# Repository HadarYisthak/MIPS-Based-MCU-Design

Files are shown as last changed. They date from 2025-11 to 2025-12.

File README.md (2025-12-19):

MIPS-Based MCU Architecture

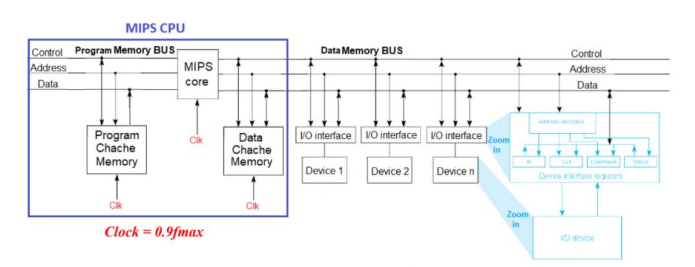
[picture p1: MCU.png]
MIPS MCU Architecture


This project implements a MIPS-based microcontroller (MCU) with Memory-Mapped I/O and interrupt support. It includes a single-cycle CPU core and essential peripheral modules, demonstrating modular microcontroller design in VHDL.

CPU Core (MIPS)
MIPS.vhd: Single-cycle processor executing fetch, decode, execute, memory access, and write-back stages.
Supports arithmetic, logical operations, branching, and memory interactions.

Peripherals
Basic Timer (BasicTimer.vhd): Up/down counting, output compare, interrupts, and PWM support.
GPIO (GPIO.vhd): Handles input/output with buttons, switches, LEDs, and generates interrupts.
Input/Output Peripheral: Separates input and output functionality for efficient communication.
Interrupt Controller (InterruptController.vhd): Manages and prioritizes external interrupts, coordinating with CPU.
Optional Address Decoder (OptAddrDecoder.vhd): Maps addresses to correct peripherals, avoiding conflicts.
Seven-Segment Decoder (SevenSegDecoder.vhd): Displays hexadecimal values on 7-segment display for debugging.

Included Files
MCU.vhd – Top-level entity
MIPS.vhd, IFETCH.vhd, IDECODE.vhd, CONTROL.vhd, ALU_CONTROL.vhd, ALU.vhd, EXECUTE.vhd, DMEMORY.vhd – CPU core modules
BasicTimer.vhd, GPIO.vhd, InputPeripheral.vhd, OutputPeripheral.vhd, InterruptController.vhd, OptAddrDecoder.vhd, SevenSegDecoder.vhd – Peripheral modules

Purpose
This project demonstrates CPU-peripheral interactions, modular microcontroller design, and hands-on VHDL programming skills, making it ideal for learning and experimentation in digital system design.

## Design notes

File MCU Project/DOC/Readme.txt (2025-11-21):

Final Project - MIPS based MCU architecture
This project aim is to design MIPS CPU core with Memory Mapped I/O and Interrupt capability 

## MCU (`MCU.vhd`)
Microcontroller unit. 

BTIMER (BasicTimer.vhd)

The Basic Timer is a dedicated hardware block found in most microcontrollers. Its primary role is straightforward – counting (either upwards or downwards, depending on configuration).
For example, an 8-bit timer will count from 0 up to 255. Once it reaches its maximum, the counter will wrap around and restart from 0.
Typically, timers can be configured through special function registers inside the microcontroller. For instance, instead of rolling over at 255, you might set the timer to reset once it reaches 100. Furthermore, timers are often connected to other hardware resources inside the MCU – for example, automatically toggling an output pin when the timer overflows.
Common timer features include:
Output Compare (OC): change the state of a pin when the timer matches a specific value.
Input Capture (IC): measure how many timer ticks occur between external events.
Pulse Width Modulation (PWM): drive a pin at specific on/off intervals by toggling it at both a match value and on overflow. By adjusting the duty cycle, you can effectively control the amount of power delivered to another device.
We’ll explore these advanced hardware functions in detail later.
For now, we’ll focus on using a timer for time measurement between events (e.g., execution time) as well as for generating basic interrupts.
In our design, the timer is configured to count upwards and to use Output Compare mode with continuous operation.

GPIO (GPIO.vhd)
The General Purpose Input/Output (GPIO) block provides a simple way to interact with the MCU through external devices such as LEDs, switches, and push buttons. It serves as the bridge between the microcontroller and the physical user interface.
Data transfer to and from the GPIO is handled through the system’s BUS lines, allowing both read and write operations as required by the application.
Additionally, the GPIO can be configured to generate interrupts – for example, pressing a button may trigger an interrupt request (IRQ), which the MCU responds to by executing an Interrupt Service Routine (ISR).
This makes the GPIO a flexible module for handling both basic input/output functionality and user-driven events

Interrupt Controller (InterruptController.vhd)
The Interrupt Controller provides support for handling external interrupts generated by hardware peripherals connected to the MCU. These interrupts are managed and prioritized according to the order defined in the project specification.
An interrupt request occurs when a peripheral asserts an IRQ signal. However, the interrupt will only be serviced if the specific interrupt is enabled and no higher-priority interrupt is already in progress.
When an interrupt is accepted, the controller initiates the interrupt handling protocol: the pipeline is stalled, remaining instructions are completed, and the address of the corresponding ISR (Interrupt Service Routine) is placed on the BUS. The actual ISR address is retrieved from memory using the appropriate Mem[type] entry, after which the MCU performs a jump to that location.
Finally, an ACK signal is sent back to confirm that the interrupt request was received and is being serviced by the processor

OptAddrDecoder (OptAddrDecoder.vhd)
The Optional Address Decoder is responsible for mapping a given address to the correct hardware component within the system. Based on the address provided on the BUS, it generates the corresponding chip select signal that activates the relevant peripheral or memory block.
This ensures that only the targeted component responds to the transaction, allowing proper communication and avoiding conflicts between multiple devices connected to the system

OutputPeripheral (OutputPeripheral.vhd)
The Output Peripheral is the part of the GPIO system dedicated specifically to handling output operations.
Its role is to manage and drive the output signals (such as LEDs or other external devices) based on the values written to it through the BUS.
By separating input and output functionality within the GPIO components, this block ensures that all output-related actions are handled in an organized and efficient way.

InputPeripheral (InputPeripheral.vhd)
The Input Peripheral is the part of the GPIO system that manages input operations.
It is responsible for capturing and providing the values from external sources, such as switches, buttons, or other input devices, and making them available to the MCU through the BUS.
This separation of input and output responsibilities within the GPIO ensures clear functionality and simplifies interaction with external hardware.

7 Segment Decoder (SevenSegDecoder.vhd)
The Seven Segment Decoder is responsible for translating a given hexadecimal value into the correct segment combination required to display the corresponding digit or character on the 7-segment display of the DE10 board.
This allows numeric or simple alphanumeric data to be visually represented for debugging or user interaction

MIPS (MIPS.vhd)
The MIPS entity represents a single-cycle MIPS processor. In this architecture, all stages of instruction execution — fetch, decode, execute, memory access, and write-back — are performed within a single clock cycle.
The IFETCH unit retrieves the instruction from the instruction memory using the current PC value and determines the next PC based on sequential execution, jumps, or branches.
The IDECODE unit decodes the fetched instruction, extracts register addresses, reads data from the register file, and computes potential branch or jump targets.
The CONTROL unit generates the required control signals by interpreting the opcode and funct fields, ensuring the correct operation for each instruction type.
The ALU_CONTROL module translates control signals into the specific operation required by the ALU.
The EXECUTE stage performs arithmetic or logical computations through the ALU, including address calculation or data manipulation as required by the instruction.
The DMEMORY unit manages reading from and writing to the data memory (RAM), enabling load and store operations.
Finally, the results are written back into the register file when needed, completing the instruction in a single clock cycle.

Included Files
MIPS.vhd — Top-level entity of the processor
IFETCH.vhd — Instruction fetch logic and PC selection
IDECODE.vhd — Instruction decode logic and register file access
CONTROL.vhd — Main control unit
ALU_CONTROL.vhd — Control signal translator for ALU operations
ALU.vhd — Arithmetic Logic Unit for computations
EXECUTE.vhd — Execution logic for ALU operations and memory addressing
DMEMORY.vhd — Data memory (RAM) interface

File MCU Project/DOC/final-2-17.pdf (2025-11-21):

``

## המערכת

בפרויקט הזה נבנה MCU המכיל MIPS ורכיבים פריפריאליים הפועלים בתיאום כמערכת. המעבד שאותו נעשה הינו מעבד CYCLE SINGLE אותו בנינו במעבדה 5 לצורך הוספת הפקודות התומכות ב ISAשל MIPS לפני מעבר ל PIPELINE.

הרכיבים הפריפריאליים אותם הוספנו הינם GPIO,TIMER BASIC ו CONTROLLER INTERRUPT. המערכת מתקשרת על ידי 3 BUS שונים: ADDRESSBUS,DATABUS ו CONROLBUS.

את המערכת נצרוב על בקר אינטל STANDART 10DE FPGA בו נביא לידי ביטוי את הרצת התוכנית על ידי שימוש בלחצנים, מתגים, נורות, לדים וגל PWM.

המתואר על ידי האיור הבא:

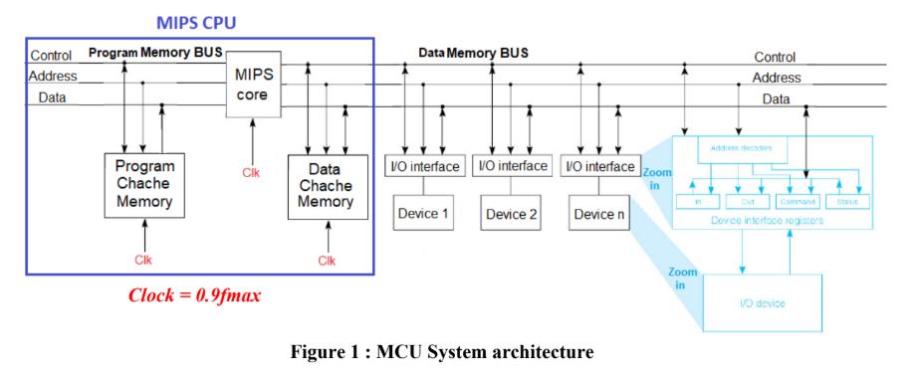
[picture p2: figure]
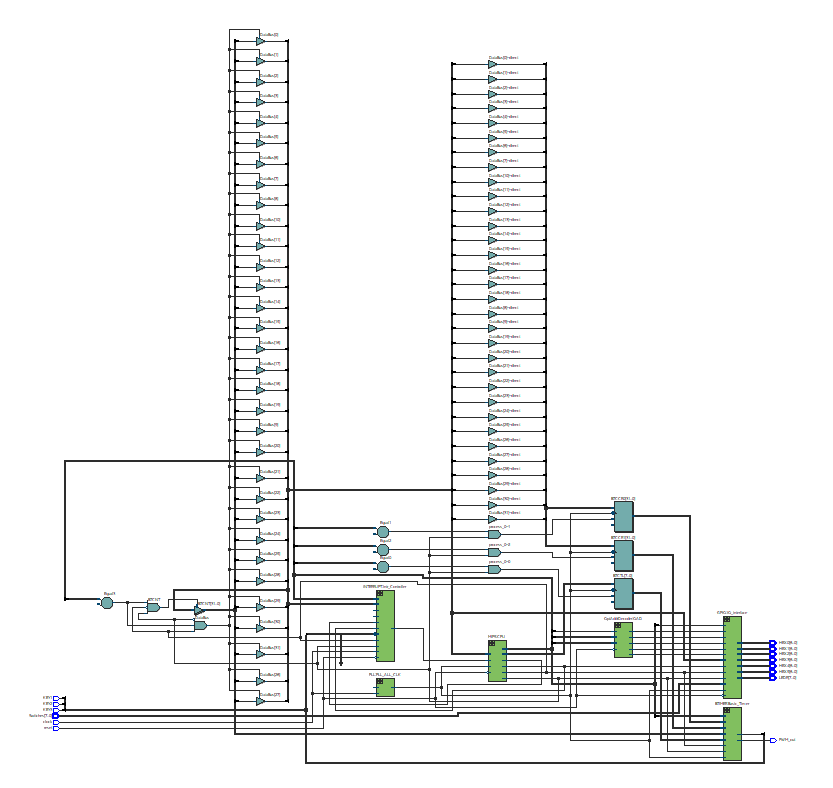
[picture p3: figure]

שרטוט ה RTL של המערכת הינו:

## החלקים השונים של המערכת:

## MIPS

רכיב ה CPU של ה MCU, הינו מעבד CYCLE SINGLE, המבצע את כל שלבי הפעולה תחת אותו מחזור. כלומר מחזור השעון של המעבד נקבע על ידי הפעולה הארוכה ביותר שהיא פעולת ה LW. המעבד יודע לתמוך בסט הפקודות אותן ביקשנו להוציא לפועל.

דיאגרמת RTL של הMIPS:

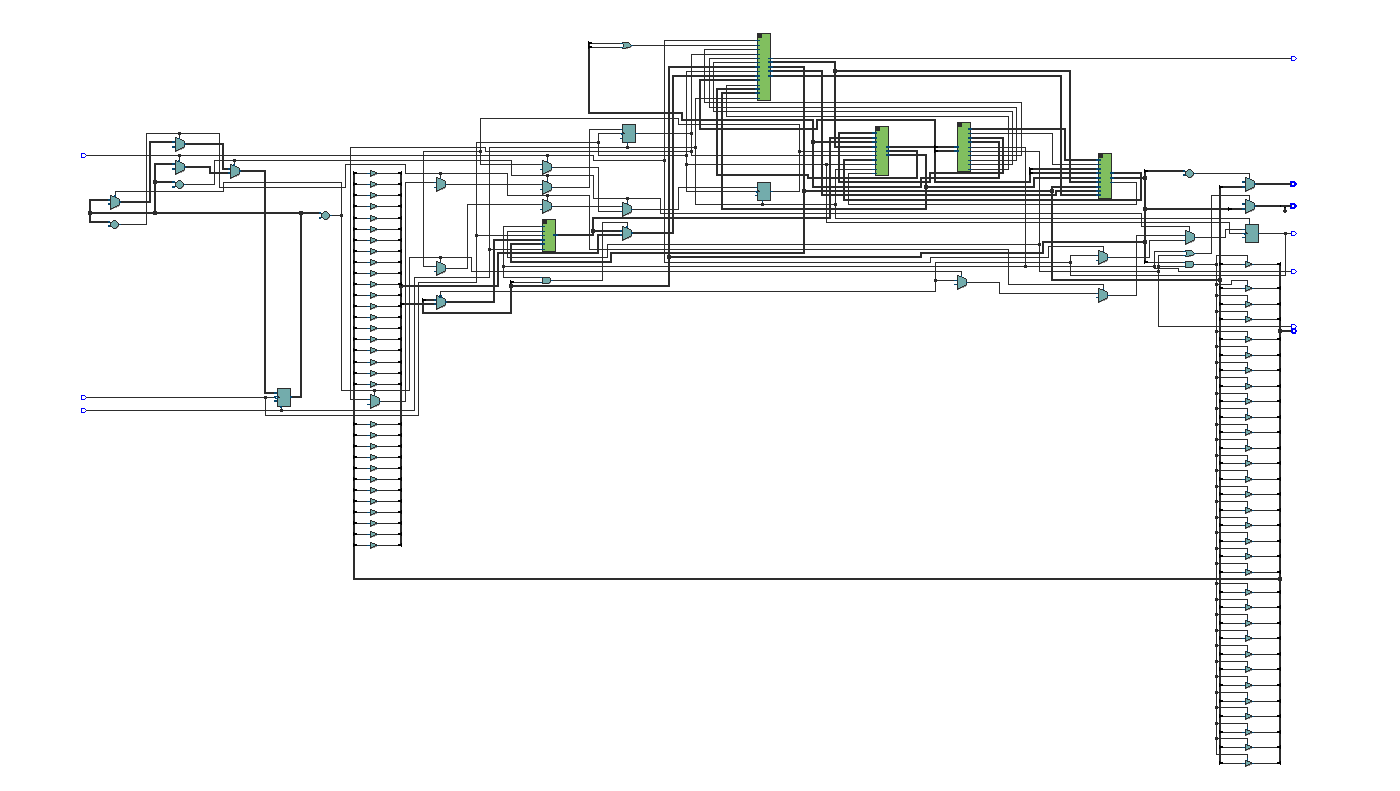
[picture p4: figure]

הלוגיקה שביצענו לעיבוד פקודות במעבד מחולקת לפי שלבי עיבוד הפעולה שהן: ,FETCH DECODE,EXECUTE, DEMEMORY, WRITE BACK.

נפרט פה על שלבי ה פעולה:

:FETCH

בשלב זה נביא את הפקודה המתאימה מתוך ה־ ITCMלפי ערך ה־ PC הנוכחי. במקביל, נחשב גם את ערך ה־ PCלמחזור הבא בעזרת שני MUX:

.1 MUXראשון –בוחר את כתובת ה־ PCהבאה מבין:

- 4 + PCהמשך רצף רגיל
- כתובת מטרה של JUMP
- כתובת מטרה של BRANCH

.2 MUXשני –מקבל כקלט את הפלט של ה־ MUXהראשון, ובוחר בין:

- ה־ PCשנבחר ב־ MUXהראשון
- כתובת היעד של פסיקה (Interrupt(

RTL של שלב ה FETCH:

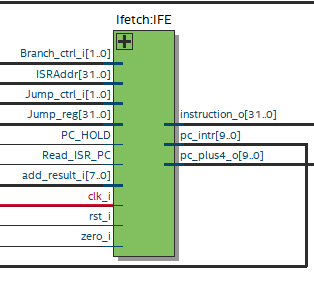
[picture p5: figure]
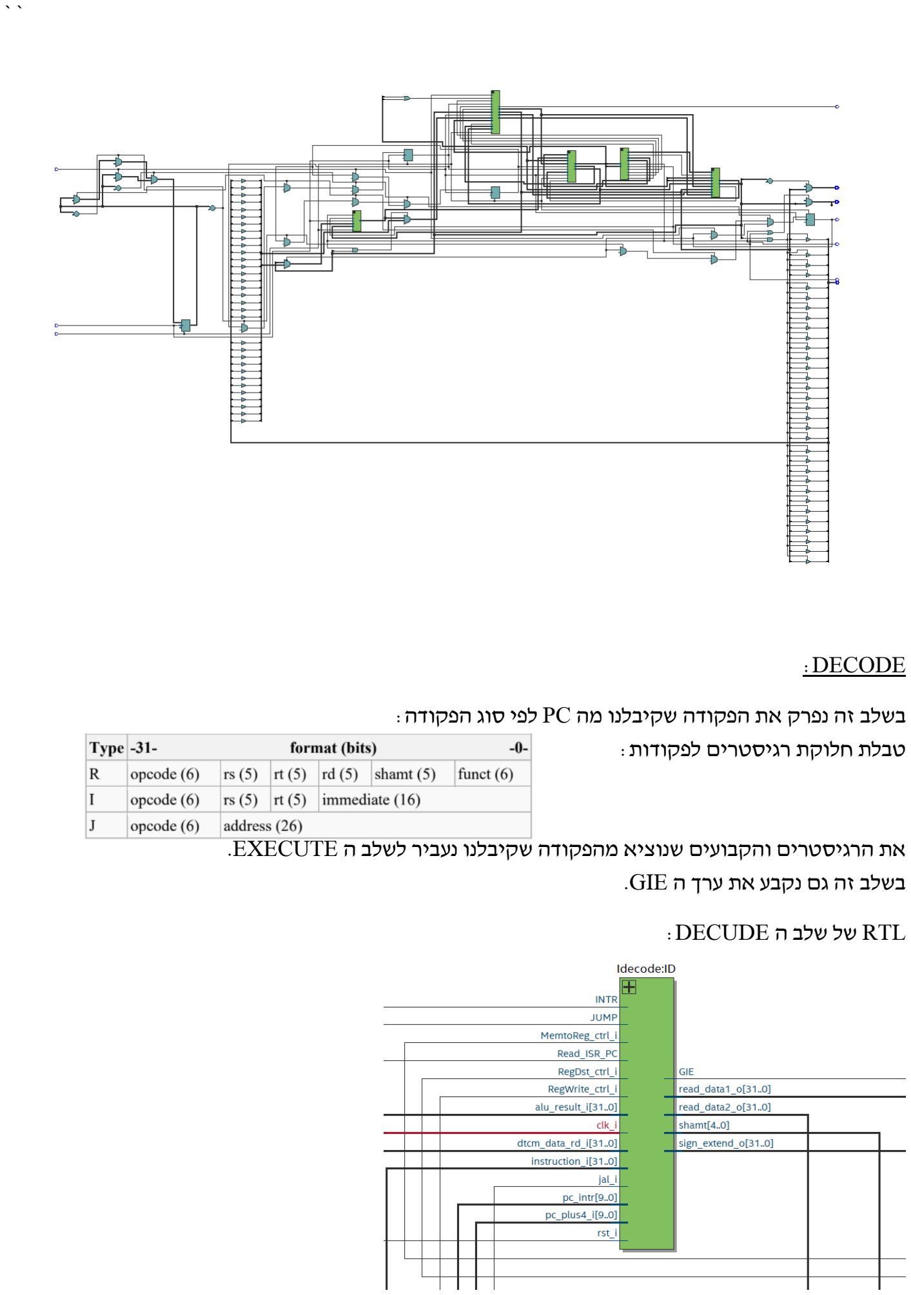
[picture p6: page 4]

:DECODE

בשלב זה נ פרק את הפקודה שקיבלנו מה PC לפי סוג הפקודה: טבלת חלוקת רגיסטרים לפקודות:

את הרגיסטרים והקבועים שנוציא מהפקודה שקיבלנו נעביר לשלב ה EXECUTE. בשלב זה גם נקבע את ערך ה GIE.

RTL של שלב ה DECUDE:

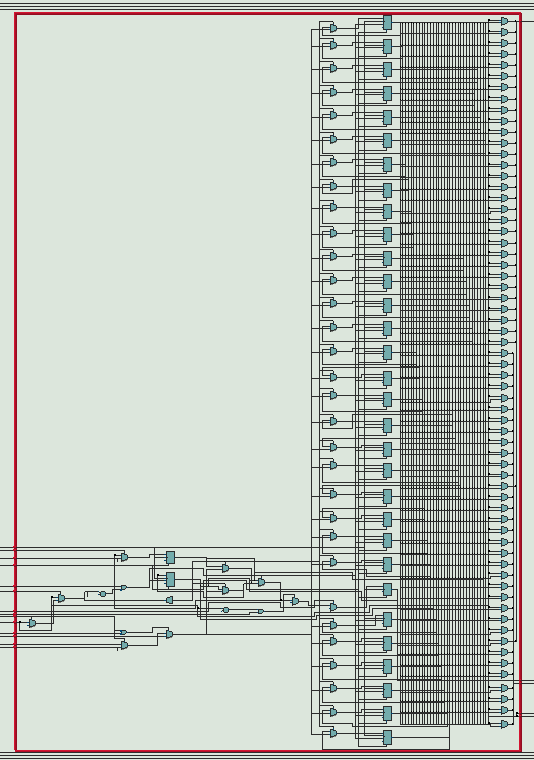
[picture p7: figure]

:EXECUTE

בשלב זה המעבד מחשב את החישוב הנדרש מהפקודה, פעולות אריתמטיות, לוגיות והזזה. במעבד CYCLE SINGLE כל ההוראה מתבצעת במחזור אחד, ולכן שלב ה־ EXאחראי לחשב את התוצאה לפני המעבר לשלב ה־ MEMאו ל־ .WB

הפעולות שמתבצעות בשלב EX

.1 חישוב כתובת לזיכרון (Store/Load(

.2 ביצוע חישוב אריתמטי/לוגי (type-I / type-R(

RTL שלב ה EX:

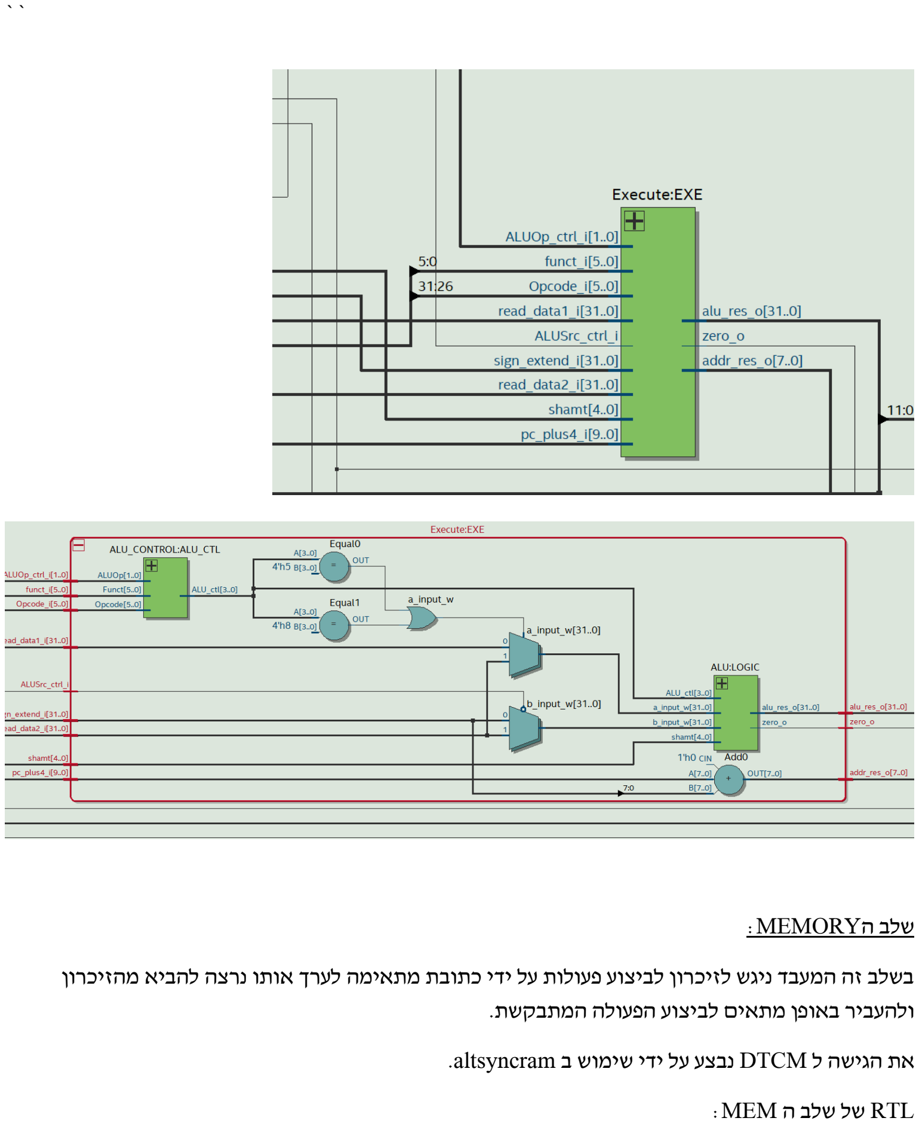
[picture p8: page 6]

שלב הMEMORY:

בשלב זה המעבד ניגש לזיכרון לביצוע פעולות על ידי כתובת מתאימה לערך אותו נרצה להביא מהזיכרון ולהעביר באופן מתאים לביצוע הפעולה המתבקשת.

את הגישה ל DTCM נבצע על ידי שימוש ב altsyncram.

RTL של שלב ה MEM:

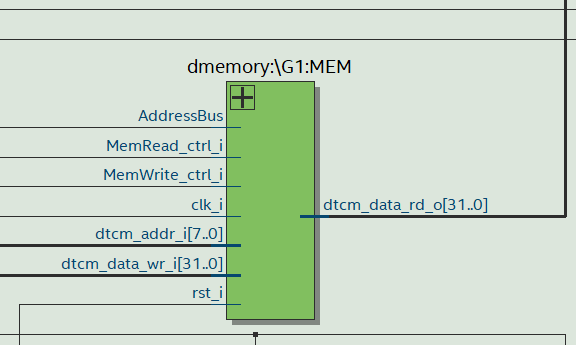
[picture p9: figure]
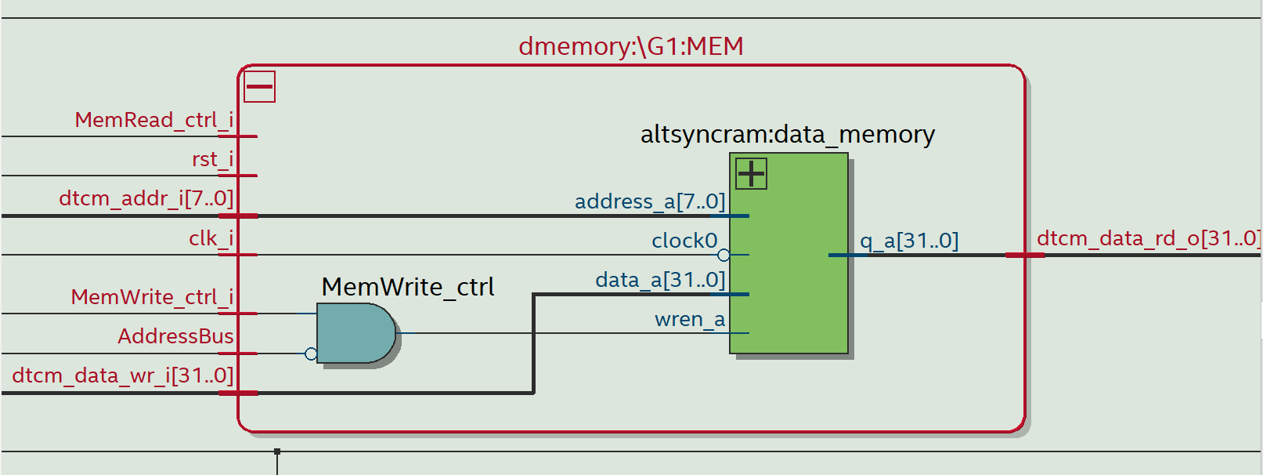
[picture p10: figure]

:WB

שלב כתיבת הערך לזיכרון או לרגיסטר המתאים.

:CONTROL

יחידה המעלה את כל קווי הבקרה הנדרשים לפעילות התקינה של הפקודות במעבד לפי סוג הפקודה שצריכה להתבצע.

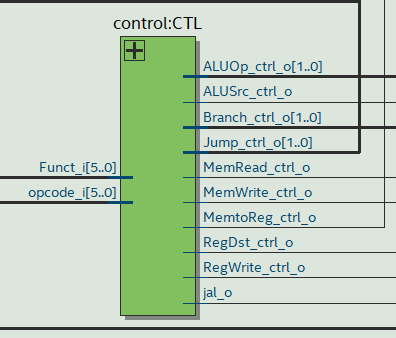
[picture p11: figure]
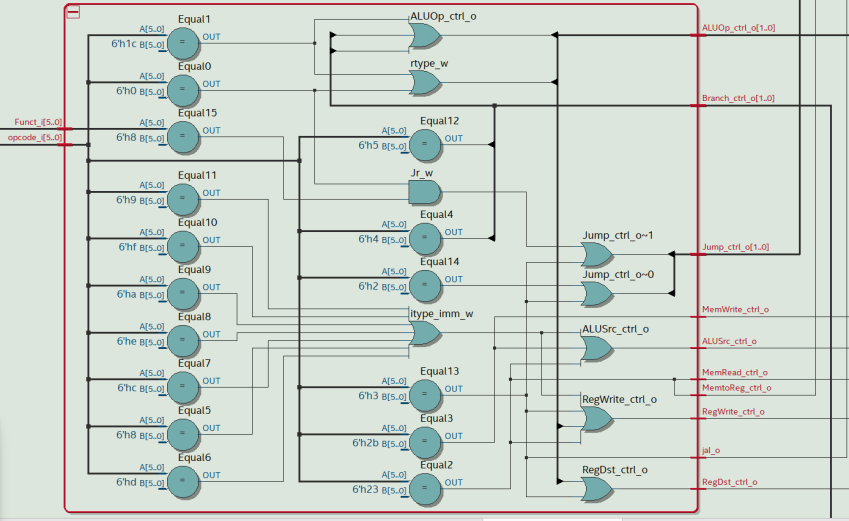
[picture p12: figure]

## רכיבים פריפריאליים:

## :BASIC TIMER

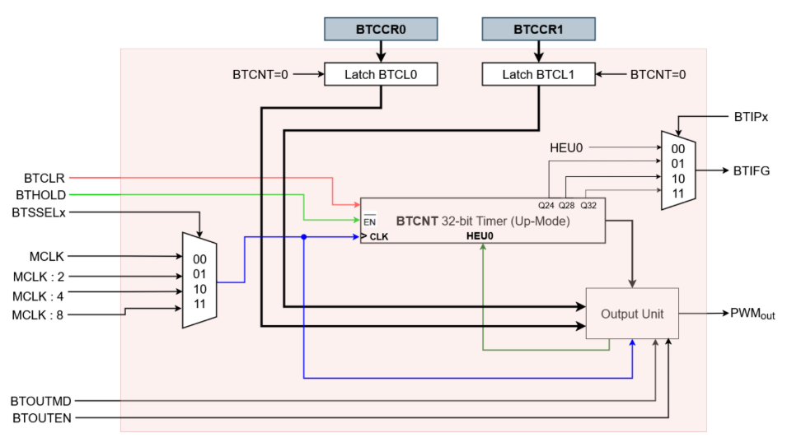
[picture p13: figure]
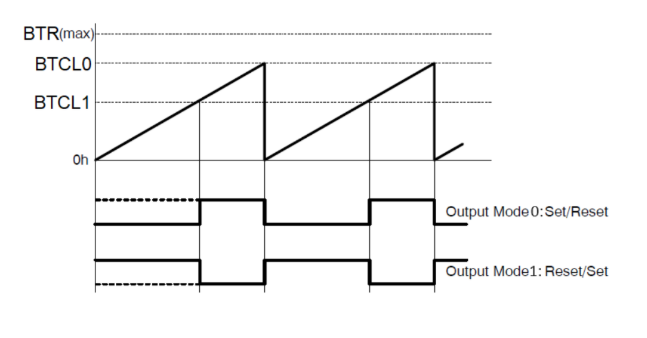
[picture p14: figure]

רכיב זה סופר על סמך עליות שעון של CLK השונה מ MCLK בעקבות חלוקה בערך קבוע DIV היוצר שעון איטי יותר בפקטור של ,2 .4,8

רכיב זה מחזיק רגיסטר בקרה בו שמורים כל אותות הבקרה הנדרשים לרכיב זה כמו HOLD,CLR וכו.. בכתובת ידוע מראש המוקצת לרגיסטר זה.

הערכים הנכנסים לרכיב זה הינם גם שמורים בכתובת ידועה בזיכרון והם יהוו לנו המונים של הרכיב שמייצרים את הגל הריבועי.

ברכיב זה יש מונה BTCNT המונה עד 0CCR ובהגעה ל 1CCR או 0CCR משתנה מוצא ה PWM כל בעצם ניצור גל ריבועי.

בנוסף ברכיב זה יש אות המודיע על INTERRUPT על פי MUX המוגדר במטלה.

דיאגרמת RTL של רכיב זה:

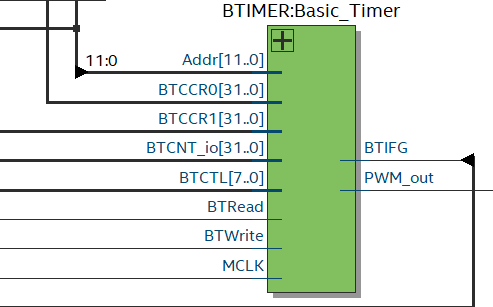
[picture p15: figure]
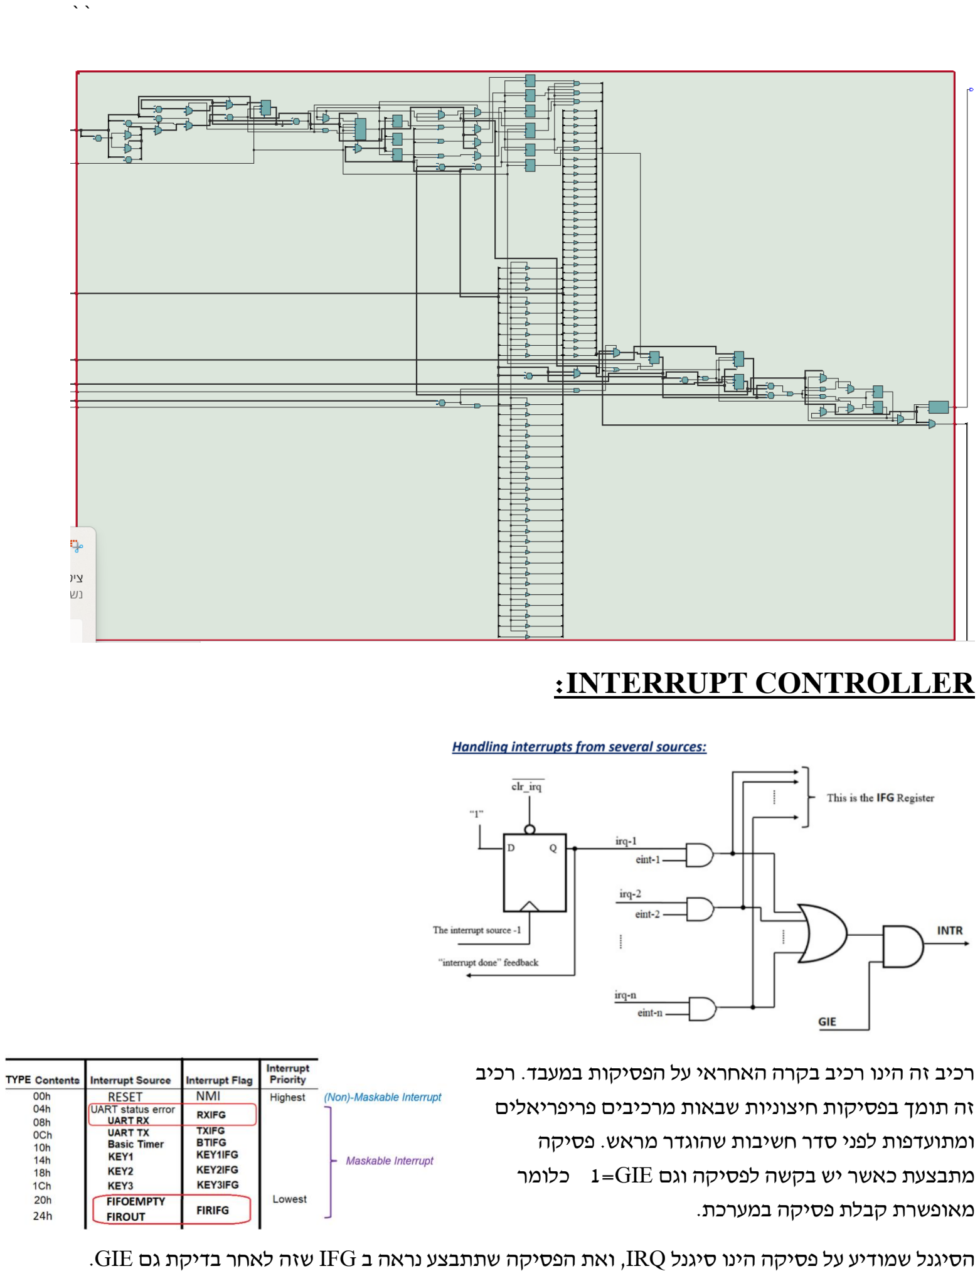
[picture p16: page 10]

## :INTERRUPT CONTROLLER

רכיב זה הינו רכיב בקרה האחראי על הפסיקות במעבד. רכיב זה תומך בפסיקות חיצוניות שבאות מרכיבים פריפריאלים ומתועדפות לפני סדר חשיבות שהוגדר מראש. פסיקה מתבצעת כאשר יש בקשה לפסיקה וגם GIE =1 כלומר מאופשרת קבלת פסיקה במערכת.

הסיגנל שמודיע על פסיקה הינו סיגנל IRQ, ואת הפסיקה שתתבצע נראה ב IFG שזה לאחר בדיקת גם GIE.

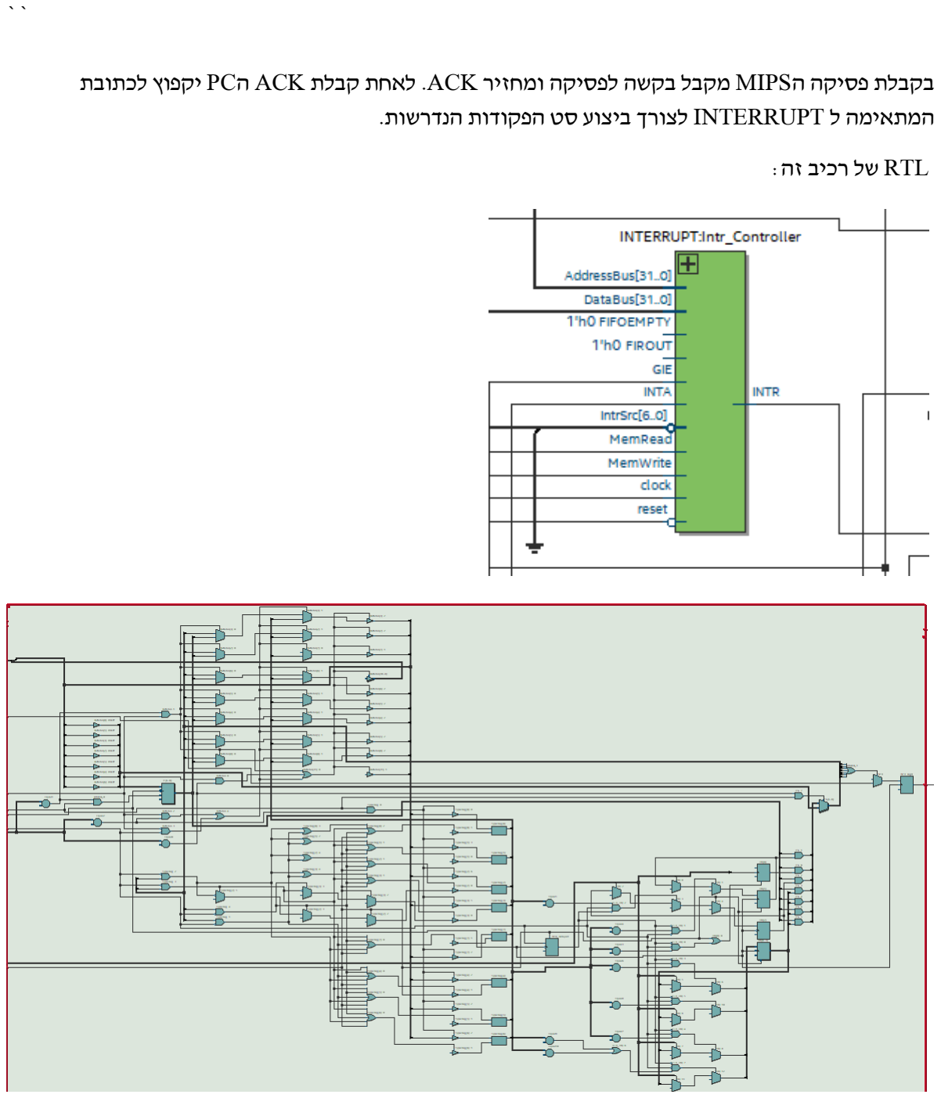
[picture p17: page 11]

בקבלת פסיקה הMIPS מקבל בקשה לפסיקה ומחזיר ACK. לאחת קבלת ACK הPC יקפוץ לכתובת המתאימה ל INTERRUPT לצורך ביצוע סט הפקודות הנדרשות.

RTL של רכיב זה:

## :GPIO

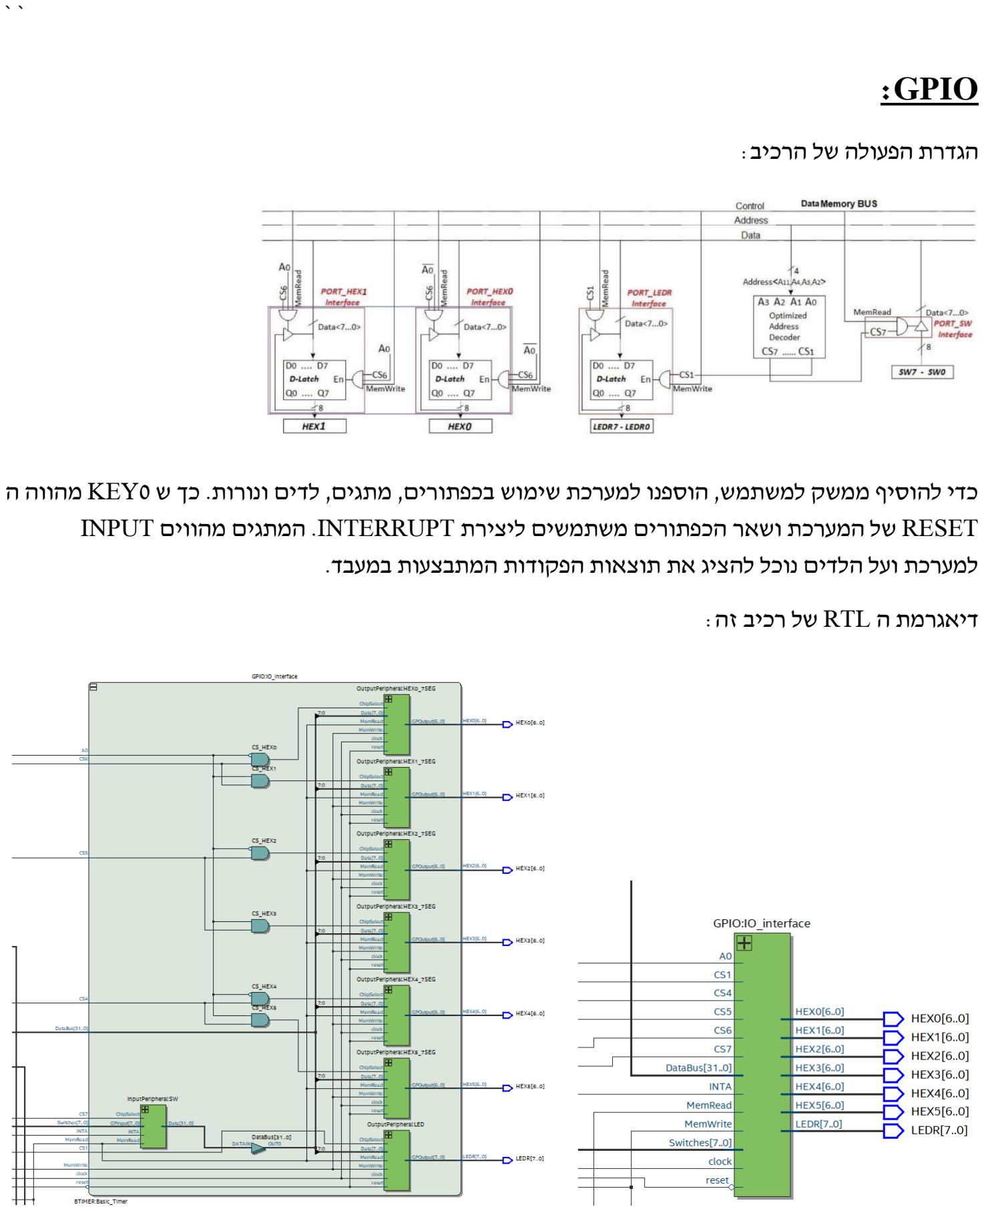
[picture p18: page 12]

הגדרת הפעולה של הרכיב:

כדי להוסיף ממשק למשתמש, הוספנו למערכת שימוש בכפתורים, מתגים, לדים ונורות. כך ש 0KEY מהווה ה RESET של המערכת ושאר הכפתורים משתמשים ליצירת INTERRUPT. המתגים מהווים INPUT למערכת ועל הלדים נוכל להציג את תוצאות הפקודות המתבצעות במעבד.

דיאגרמת ה RTL של רכיב זה:

## נתיב קריטי:

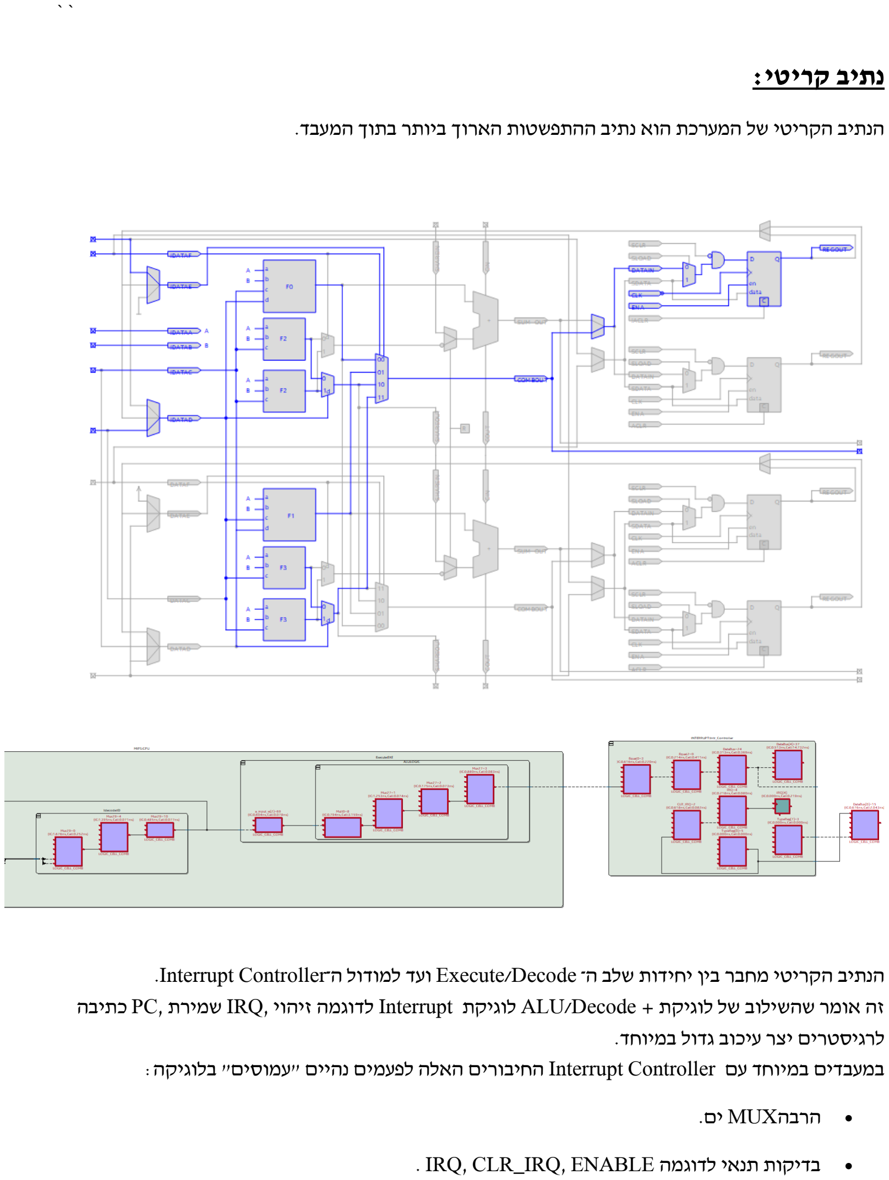
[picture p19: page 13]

הנתיב הקריטי של המערכת הוא נתיב ההתפשטות הארוך ביותר בתוך המעבד.

הנתיב הקריטי מחבר בין יחידות שלב ה־ Decode/Execute ועד למודול ה־Controller Interrupt. זה אומר שהשילוב של לוגיקת + Decode/ALU לוגיקת Interrupt לדוגמה זיהוי ,IRQ שמירת ,PC כתיבה לרגיסטרים יצר עיכוב גדול במיוחד. במעבדים במיוחד עם Controller Interrupt החיבורים האלה לפעמים נהיים "עמוסים" בלוגיקה:

- הרבהMUX ים.
. IRQ, CLR_IRQ, ENABLE | לדוגמה | תנאי | בדיקות | •

- כתיבה/קריאה לרגיסטרים פנימיים.

כל זה נערם לנתיב לוגי ארוך שזהו הנתיב הקריטי.

היינו משפרים את הנתיב הקריטי על ידי מעבר לPIPELINE: חציצת המערכת על ידי רגיסטרים יגרום למערכת להתנהל לפי מחזור שעון מקסימלי בין רגיסטרים. כלומר, חציצה שכזאת תגרום למחזור שעון להיות קצר יותר מאשר של מעבד ה CYCLE SINGLE. כך, שלמרות שלכל פעולה יהיו יותר מחזורי שעון זמן התוכנית הכולל יהיה קצר יותר מכיוון שהפעולות יעבדו במקביל.

בנוסף, היינו מנסים לייעל את הנתיב הקריטי של המערכת על מנת לצמצם MUXים לדוגמה.

## התדר המקסימלי של המערכת הינו:

## ניתוח תוצאות:

לאחר כתיבת קבצי VHDL העלנו את הקבצים לתוכנת ה QUARTUS שם הרצנו טסטים בעזרת SIGNAL TAP להלן הניתוח ביצועים של הטסטים שהרצנו.

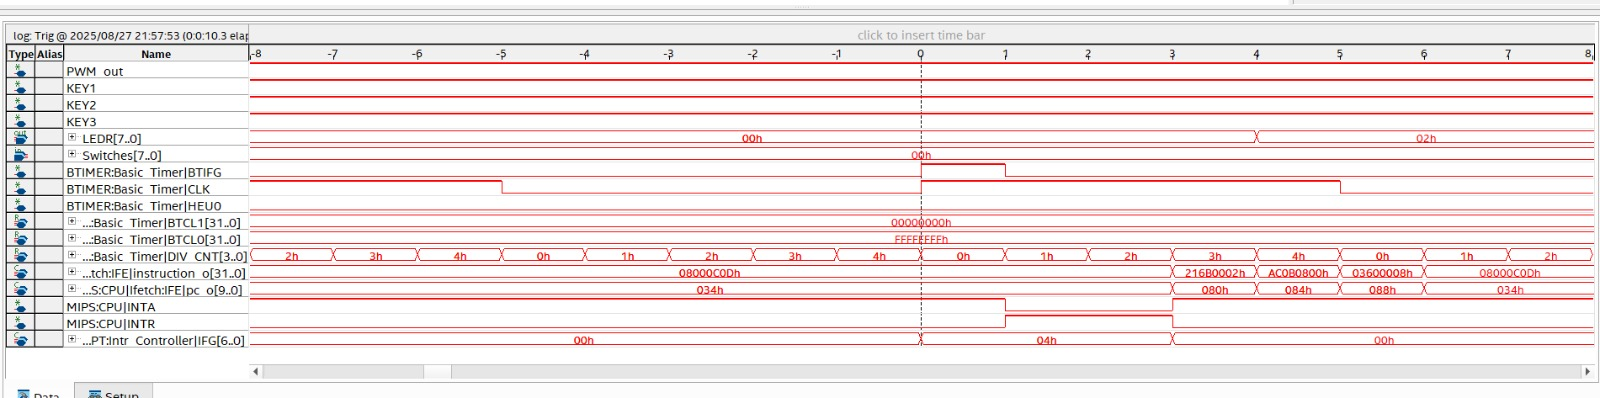
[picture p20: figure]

טסט 3 –

כפי שניתן לראות עבור טסט זה הגדרנו את הטריגר כעליית השעון של האינטרפט המגיע מהטיימר, בנקודה זו בה הביט ה24- מתהפך עולה האינטרפט ובעקבותיו ניתן לראות כי ערך הלדים גדל ב2- בעקבות שגרת האינטרפט.
ניתן לראות כי הפעולה המבוצעת על פי שורת ה-instruction היא לולאה אינסופית עד אשר מגיע האינטרפט

ומוציא לשגרה ובנוסף ניתן לראות את בקשת האינטרפט והמענה אליו בסיגנלים: INTA,INTR מגיבים בהתאפ ואת וקטור ה- IFG משתנה כך שנדלק הביט השלישי שמציין את הטיפול באינטרפט מהטיימר.

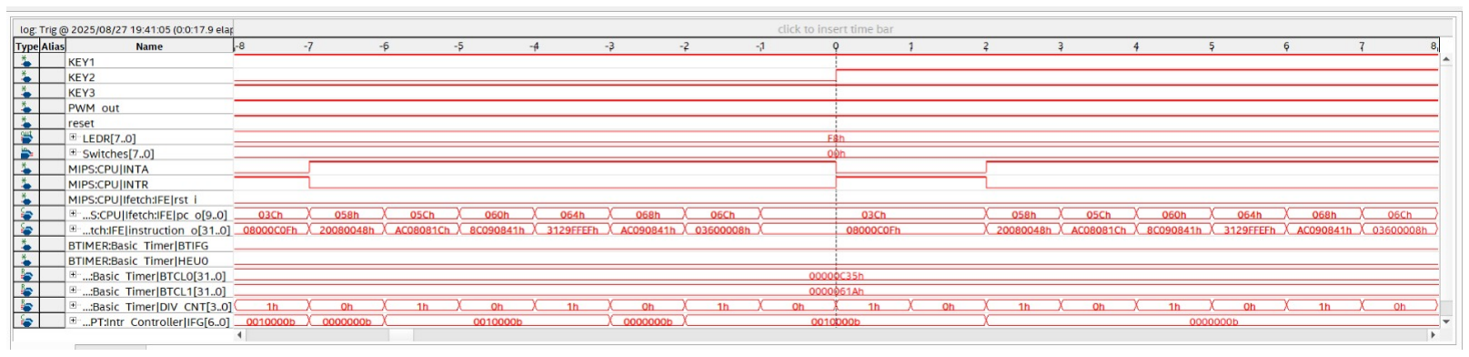
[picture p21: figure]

טסט 2 –

בטסט זה הוצאנו גל מחזורי מהבקר על פי תדר שנקבע לפי האינטרפט, ניתן לראות כי מפעולת הלולאה האינסופית ישנה קפיצה לשגרת האינטרפט ותדר השעון משתנה לחצי מהשעון הרגיל )שלפני כן היה שמינית(. בנוסף ניתן לראות את הסיגנלים הרלוונטים לטיפול באינטרפט כמו INRT,INTA, IFG נדלקים ונכבים בהתאם.

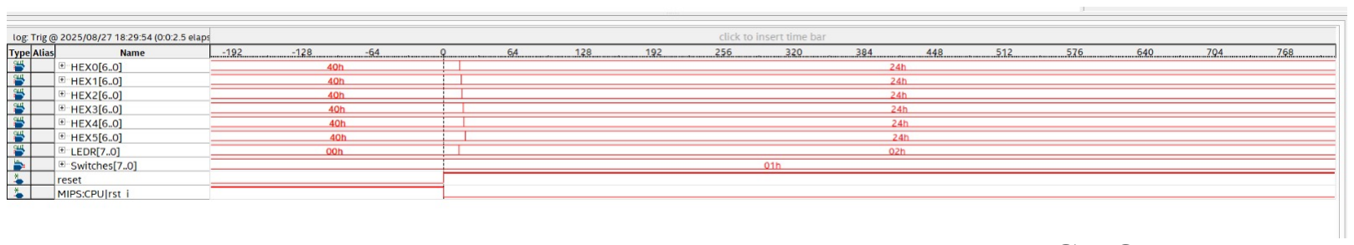
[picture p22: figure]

טסט 2 )GPIO – )

ניתן לראות איך על פי טסט זה בכל איטרציה לאחר דילאי קופץ ערך הלדים והhex ב2- לפי ה-switch, ניתן לראות בתמונה זו את האיטרציה הראשונה ובגלל הדילאי ההגדול לא מופיעה איטרציה נוספת במסך. הטריגר נתפס בעזרת ה- reset.

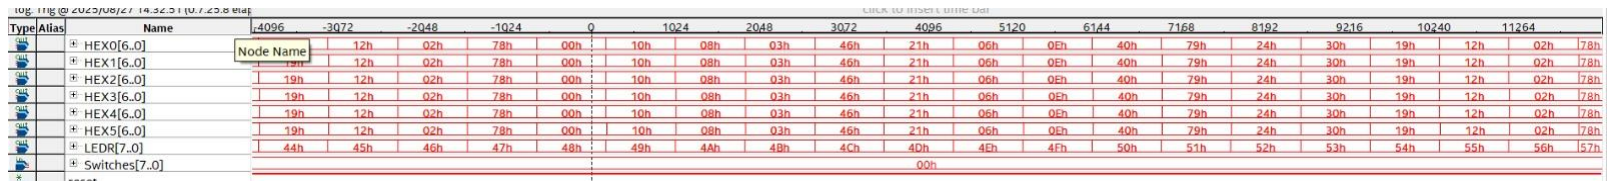
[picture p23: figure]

טסט 2 )GPIO –)

ניתן לראות את הראשון בו מבצעת ספירה מחזורית על גבי הלדים וה -HEX , בנוסף בטסט זה הורדנו את ערך הדילאי על מנת שנוכל לראות כמה שיותר שינויים על גבי הרכיבים הפריפריאלים.

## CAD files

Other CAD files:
MCU Project/QUATRUS/stp1GPIOANAIG.stp
MCU Project/QUATRUS/stp1.stp
MCU Project/QUATRUS/stp2GPIO.stp
MCU Project/QUATRUS/stp4test1.stp
MCU Project/QUATRUS/stp6test3.stp
MCU Project/QUATRUS/stp5test2.stp
